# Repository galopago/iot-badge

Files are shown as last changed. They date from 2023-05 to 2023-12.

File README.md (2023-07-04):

# IOT-BADGE

## Electronic conference badge for programming conventions, hacking events, etc.

* Open Source (designed in [KiCad](https://www.kicad.org/)), schematic files, PCB and GERBER files open, free and available
* Comfortable wearable badge, no components on the back side.
* Max size 10 x 10 cm to take advantage of cost reductions of most PCB makers.
* Can be powered by a 3.2 v LiFePO4 AAA size battery
* Compatible with TinyGS firmware for [reception of LoRa satellites](https://galopago.github.io/english/lora-satelite-ground-station/). No modifications needed!

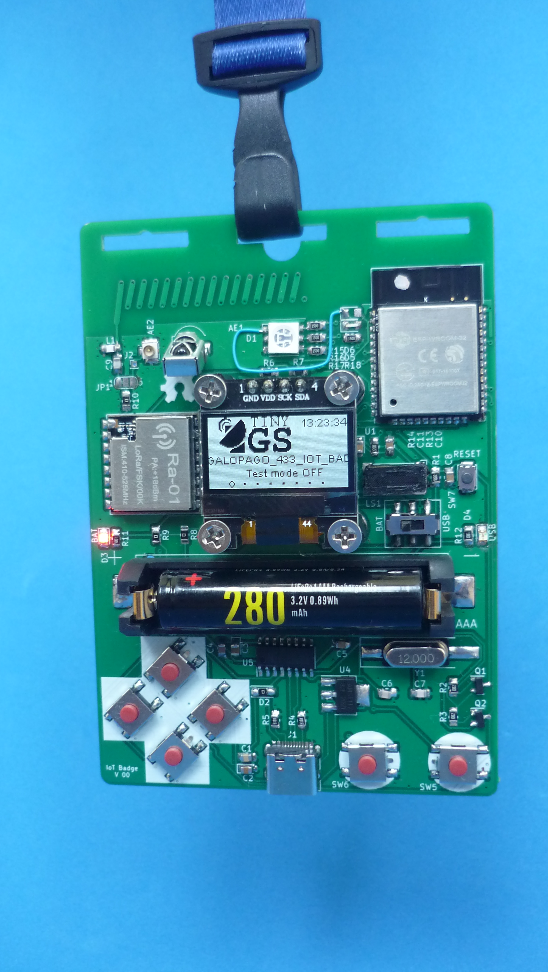
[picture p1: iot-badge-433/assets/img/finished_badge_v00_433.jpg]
Finished Badge 433 Mhz version


Read this in other languages: [Español](/iot-badge-433/assets/markdown/README.es.md)

## Block Diagram

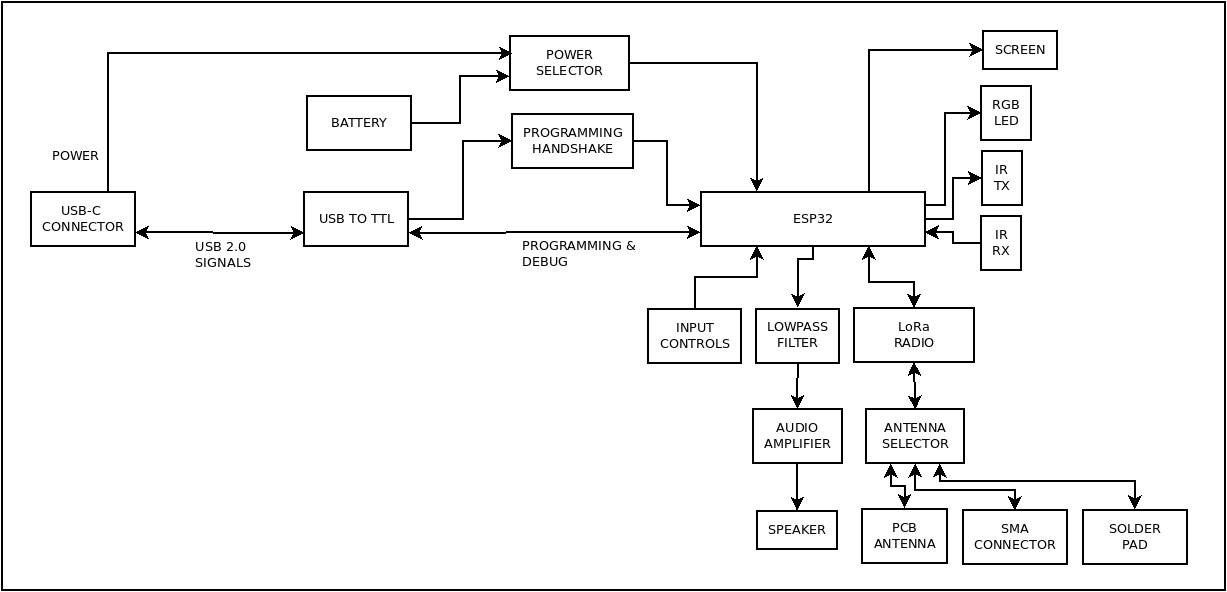
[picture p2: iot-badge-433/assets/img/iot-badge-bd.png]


## Capabilities

* ESP32 module compatible with multiple programming languages/platforms: [C/C++](https://docs.espressif.com/projects/esp-idf/en/latest/esp32/), [Arduino](https://github.com/espressif/arduino-esp32), Python (via [MicroPython](https://micropython.org/)), JavaScript (via [Espruino](https://www.espruino.com/ESP32) or [Mongoose OS](https://mongoose-os.com/)), [Rust ([via esp-rs](https://esp-rs.github.io/book/))
* 0.96" OLED display
* Infrared LED transmitter and receiver
* WiFi
* Radio transmitter and receiver module: FSK, GFSK, MSK, GMSK and LoRa!
* Onboard PCB antenna (433 Mhz and 915 Mhz versions)
* U.FL Connector for external antenna
* RGB LED
* 0.7 W speaker
* 6 buttons: 4 arranged in D-pad and 2 function buttons
* USB-C Connector

## 433 Mhz Version
Back                           | Side                                  | External Ant                          |
-------------------------------|---------------------------------------|---------------------------------------|
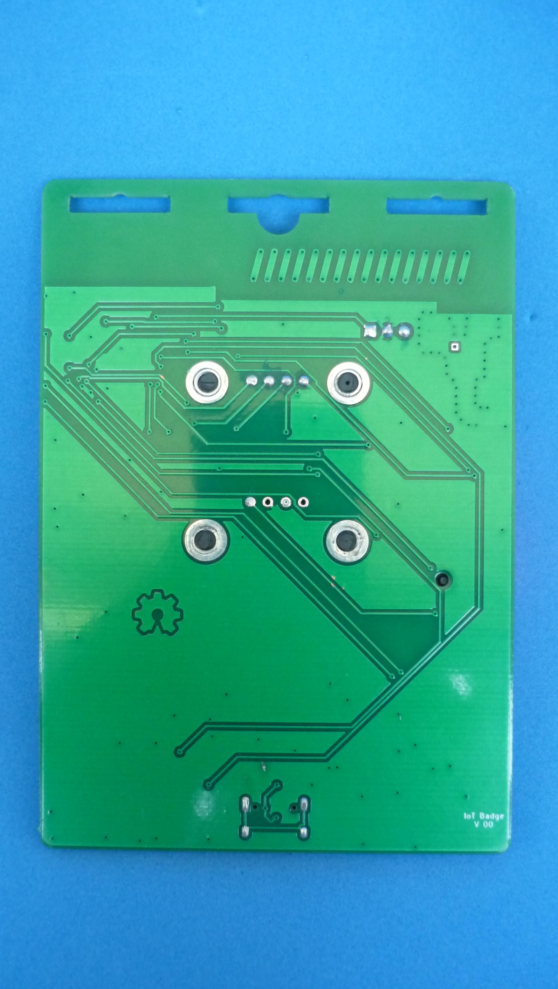
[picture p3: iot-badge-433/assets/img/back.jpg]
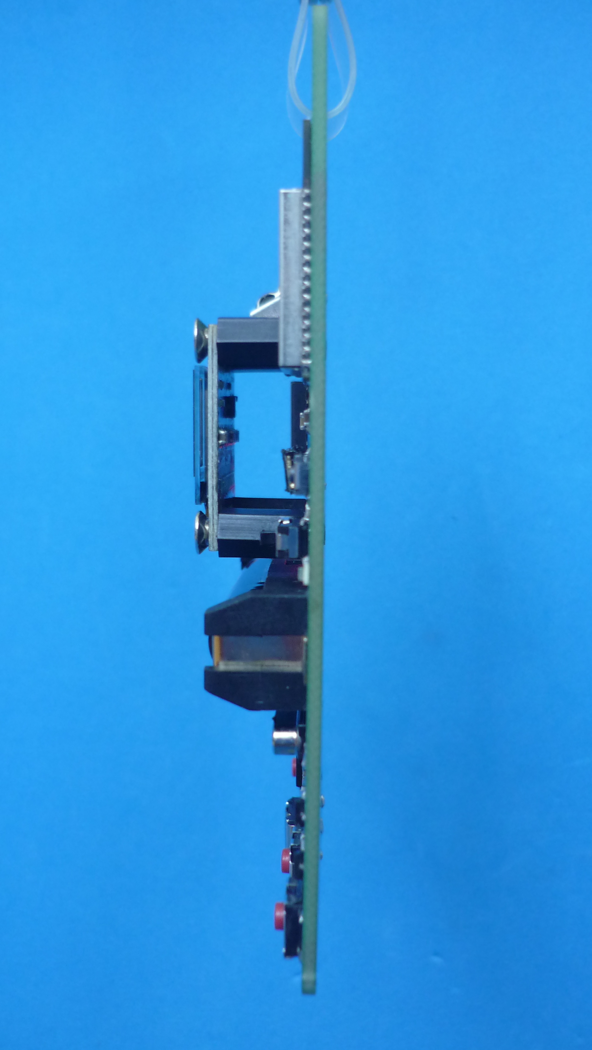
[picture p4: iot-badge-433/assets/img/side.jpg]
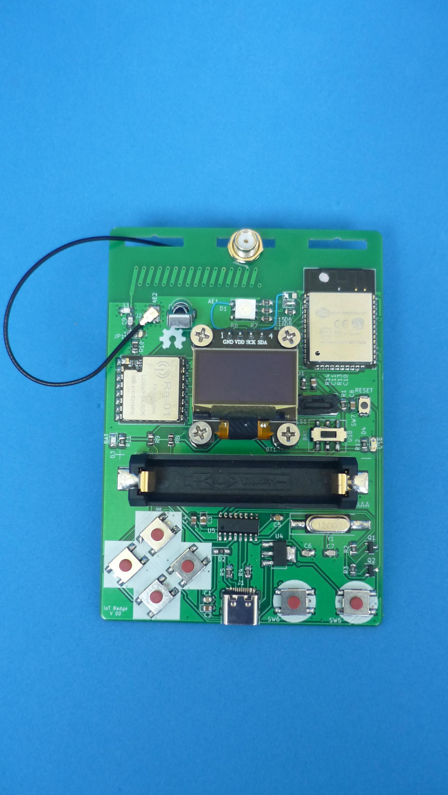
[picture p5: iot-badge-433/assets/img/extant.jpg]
| | |

## Schematic Diagram 433 Version

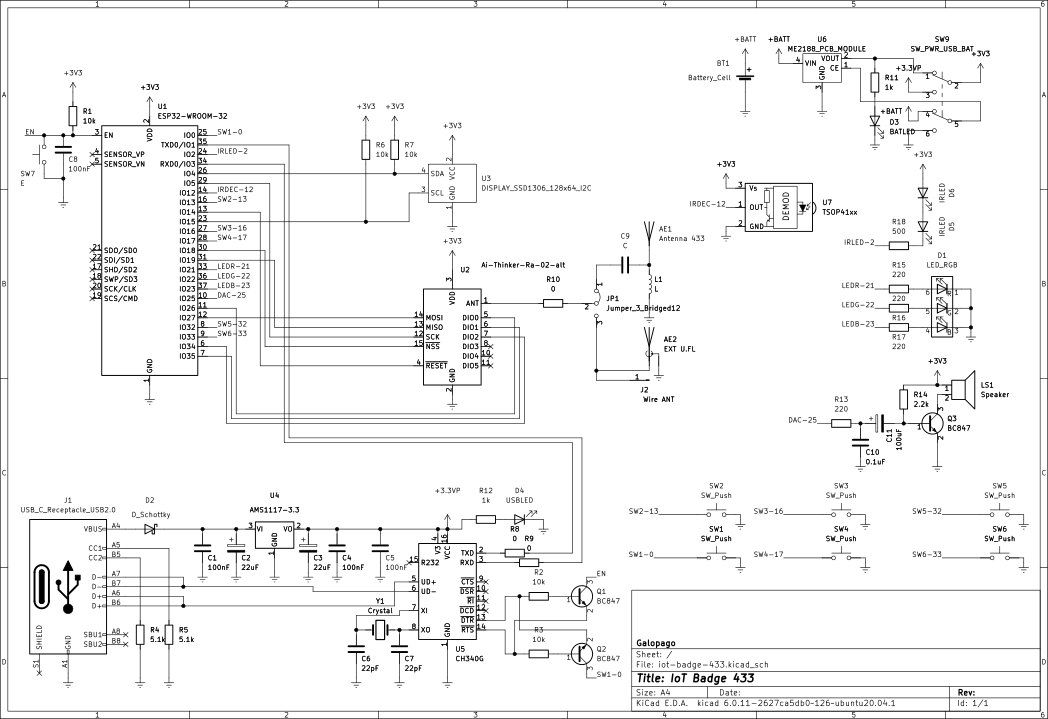
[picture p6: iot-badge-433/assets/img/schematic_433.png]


## Pinout connections

### SSD1306 128x64 i2c OLED display

ESP32 GPIO PIN |Function
---------------|---------
4              | SDA
15             | SCL

### Ra-02 LoRa module

ESP32 GPIO PIN |Function
---------------|---------
19             | POCI
27             | PICO
5              | SCK
18             | /CS

### Speaker

ESP32 GPIO PIN |Function
---------------|---------
25             | Speaker

### Buttons ( please use internal pull-ups! )

ESP32 GPIO PIN |Function
---------------|---------
0              | Up
13             | Down
16             | Left
17             | Right
33             | B
32             | A

### RGB LED

ESP32 GPIO PIN |Function
---------------|---------
21             | Red
22             | Green
23             | Blue

### Ifrared transmitter LED

ESP32 GPIO PIN |Function
---------------|---------
2              | Infrared LED

### VS1838b INFRARED RECEIVER MODULE

ESP32 GPIO PIN |Function
---------------|---------
12             | VS1838b output

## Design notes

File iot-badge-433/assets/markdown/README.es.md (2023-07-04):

# IOT-BADGE

## Gafete electronico para conferencias de programacion, eventos de hackers, etc.

* Codigo abierto (disenado en [KiCad](https://www.kicad.org/)), diagramas esquematicos, circuito impreso y archivos GERBER abiertos, gratuitos y disponibles!
* Comodo para usar, no hay componentes en la cara de atras del circuito impreso.
* Tamaño maximo 10 x 10 cm para lograr costos economicos en la fabricacion del circuito impreso que ofrecen la mayoria de fabricantes para tarjetas de dimensiones iguales o menores a esta.
* Puede ser alimentado mediante una bateria AAA LiFePO4 de 3.2 v.
* Compatible con el firmware de TinyGS [para reception de satelites LoRa ](https://galopago.github.io/espanol/lora-satelite-estacion-terrena/). No se requiere ninguna modificacion!

## Version 433 Mhz
Finished Badge

Lea esto en otros idiomas: [English](../../../README.md)

## Diagrama de bloques



## Perifericos disponibles

* Modulo ESP32 compatible con multiples lenguajes/plataformas de programacion: [C/C++](https://docs.espressif.com/projects/esp-idf/en/latest/esp32/), [Arduino](https://github.com/espressif/arduino-esp32), Python (via [MicroPython](https://micropython.org/)), JavaScript (via [Espruino](https://www.espruino.com/ESP32) or [Mongoose OS](https://mongoose-os.com/)), [Rust ([via esp-rs](https://esp-rs.github.io/book/))
* Pantalla OLED de 0.96"
* LED transmisor infrarojo y receptor.
* WiFi
* Modulo radio transmisor FSK, GFSK, MSK, GMSKde 433 Mhz y LoRa!
* Antena incorporada en el PCB (version de 433 Mhz y 915 Mhz)
* Conector U.FL para antena externa.
* LED RGB
* Bocina de 0.7 W
* 6 butone: 4 configurados como cruceta y 2 botones de funcion adicional
* Conector USB-C

Detras                         | Lateral                               | Antena Externa                        |
-------------------------------|---------------------------------------|---------------------------------------|
| | |

## Diagrama Esquematico



## Conexiones de pines entre los perifericos y el modulo ESP32

### Pantalla OLED i2c SSD1306 128x64

ESP32 GPIO PIN |Funcion
---------------|---------
4              | SDA
15             | SCL

### modulo LoRa Ra-02

ESP32 GPIO PIN |Funcion
---------------|---------
19             | POCI
27             | PICO
5              | SCK
18             | /CS

### Bocina

ESP32 GPIO PIN |Funcion
---------------|---------
25             | Bocina

### Butones ( hay que usar internos! )

ESP32 GPIO PIN |Funcion
---------------|---------
0              | Arriba
13             | Abajo
16             | Izquierda
17             | Derecha
33             | B
32             | A

### LED RGB

ESP32 GPIO PIN |Funcion
---------------|---------
21             | Rojo
22             | Verde
23             | Azul

### LED Infrarojo transmisor

ESP32 GPIO PIN |Funcion
---------------|---------
2              | LED Infrarojo

### MODULO RECEPTOR INFRAROJO VS1838b

ESP32 GPIO PIN |Funcion
---------------|---------
12             | salida del VS1838b

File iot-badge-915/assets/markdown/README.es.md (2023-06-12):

# IOT-BADGE

## Gafete electronico para conferencias de programacion, eventos de hackers, etc.

* Codigo abierto (disenado en [KiCad](https://www.kicad.org/)), diagramas esquematicos, circuito impreso y archivos GERBER abiertos, gratuitos y disponibles!
* Comodo para usar, no hay componentes en la cara de atras del circuito impreso.
* Tamaño maximo 10 x 10 cm para lograr costos economicos en la fabricacion del circuito impreso que ofrecen la mayoria de fabricantes para tarjetas de dimensiones iguales o menores a esta.
* Puede ser alimentado mediante una bateria AAA LiFePO4 de 3.2 v.
* Compatible con el firmware de TinyGS [para reception de satelites LoRa ](https://galopago.github.io/espanol/lora-satelite-estacion-terrena/). No se requiere ninguna modificacion!

Finished Badge

Lea esto en otros idiomas: [English](../../README.md)

## Diagrama de bloques



## Perifericos disponibles

* Modulo ESP32 compatible con multiples lenguajes/plataformas de programacion: [C/C++](https://docs.espressif.com/projects/esp-idf/en/latest/esp32/), [Arduino](https://github.com/espressif/arduino-esp32), Python (via [MicroPython](https://micropython.org/)), JavaScript (via [Espruino](https://www.espruino.com/ESP32) or [Mongoose OS](https://mongoose-os.com/)), [Rust ([via esp-rs](https://esp-rs.github.io/book/))
* Pantalla OLED de 0.96"
* LED transmisor infrarojo y receptor.
* WiFi
* Radio transmisor de 433 Mhz (incluyendo LoRa) conectado a una antena interna formada en el circuito impreso!
* Conector U.FL para antena externa de 433 Mhz.
* LED RGB
* Bocina de 0.7 W
* 6 butone: 4 configurados como cruceta y 2 botones de funcion adicional
* Conector USB-C

Detras                         | Lateral                               | Antena Externa                        |
-------------------------------|---------------------------------------|---------------------------------------|
| | |

## Diagrama Esquematico

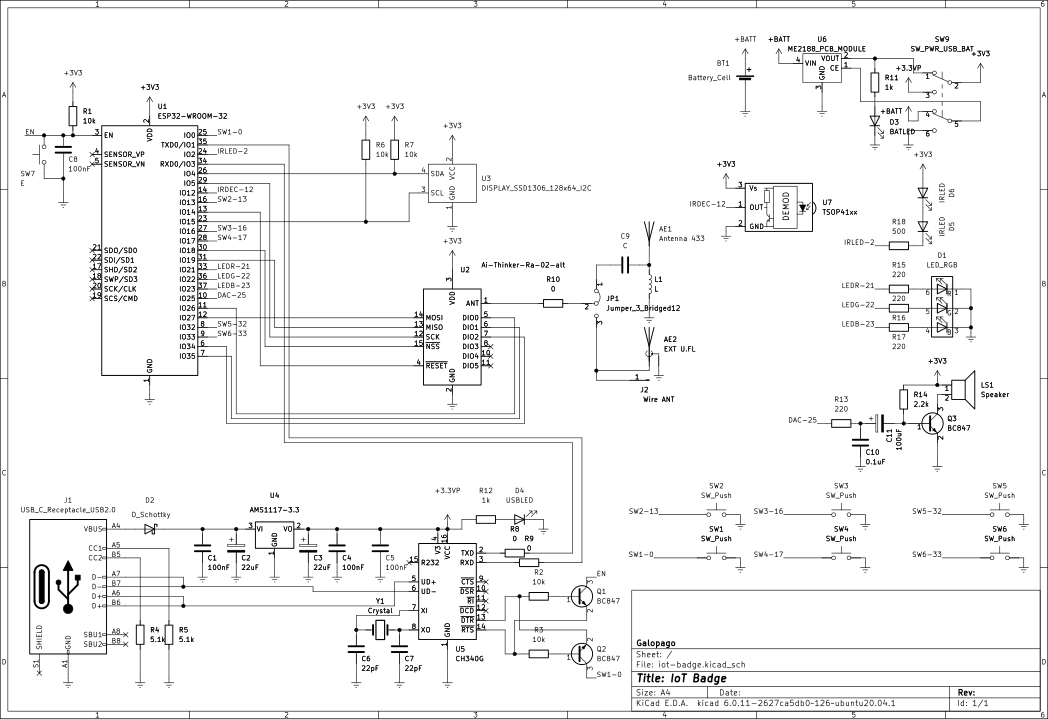
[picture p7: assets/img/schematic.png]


## Conexiones de pines entre los perifericos y el modulo ESP32

### Pantalla OLED i2c SSD1306 128x64

ESP32 GPIO PIN |Funcion
---------------|---------
4              | SDA
15             | SCL

### modulo LoRa Ra-02

ESP32 GPIO PIN |Funcion
---------------|---------
19             | POCI
27             | PICO
5              | SCK
18             | /CS

### Bocina

ESP32 GPIO PIN |Funcion
---------------|---------
25             | Bocina

### Butones ( hay que usar internos! )

ESP32 GPIO PIN |Funcion
---------------|---------
0              | Arriba
13             | Abajo
16             | Izquierda
17             | Derecha
33             | B
32             | A

### LED RGB

ESP32 GPIO PIN |Funcion
---------------|---------
21             | Rojo
22             | Verde
23             | Azul

### LED Infrarojo transmisor

ESP32 GPIO PIN |Funcion
---------------|---------
2              | LED Infrarojo

### MODULO RECEPTOR INFRAROJO VS1838b

ESP32 GPIO PIN |Funcion
---------------|---------
12             | salida del VS1838b

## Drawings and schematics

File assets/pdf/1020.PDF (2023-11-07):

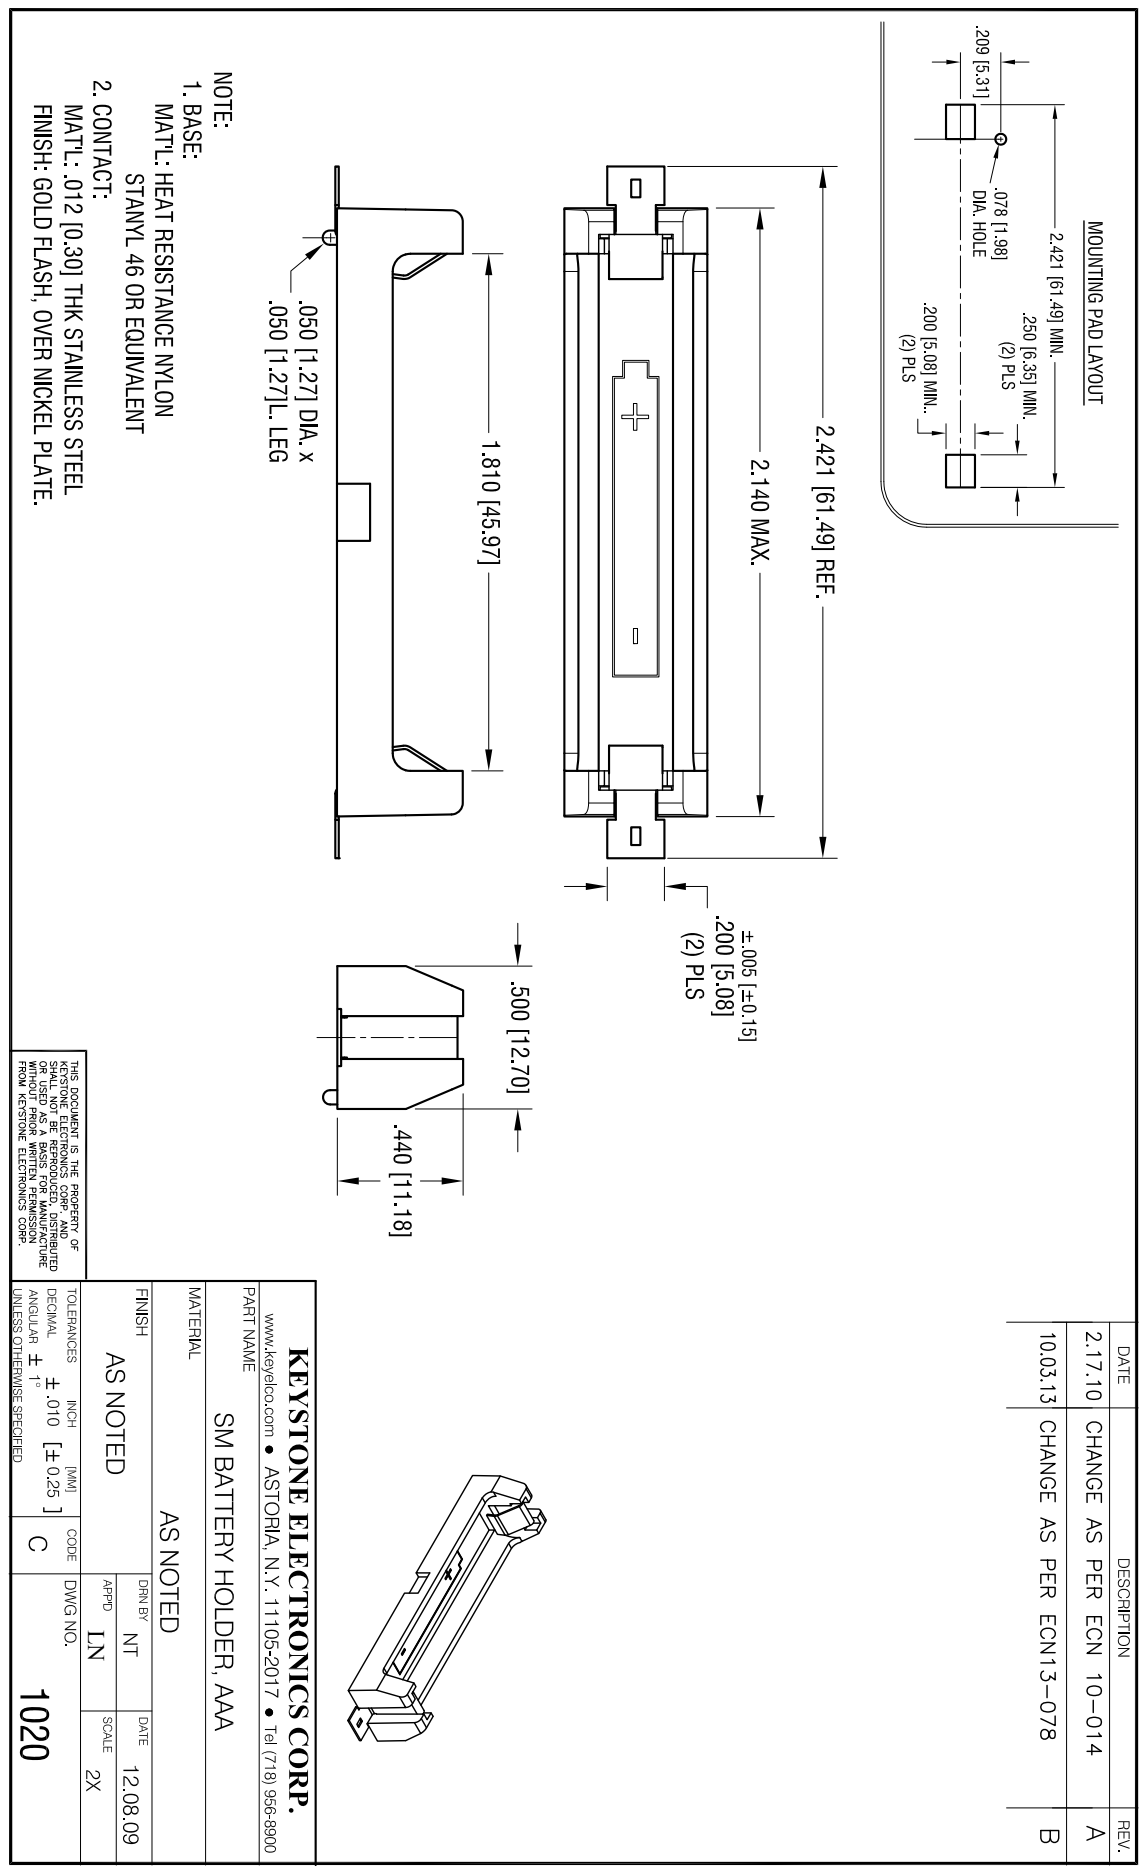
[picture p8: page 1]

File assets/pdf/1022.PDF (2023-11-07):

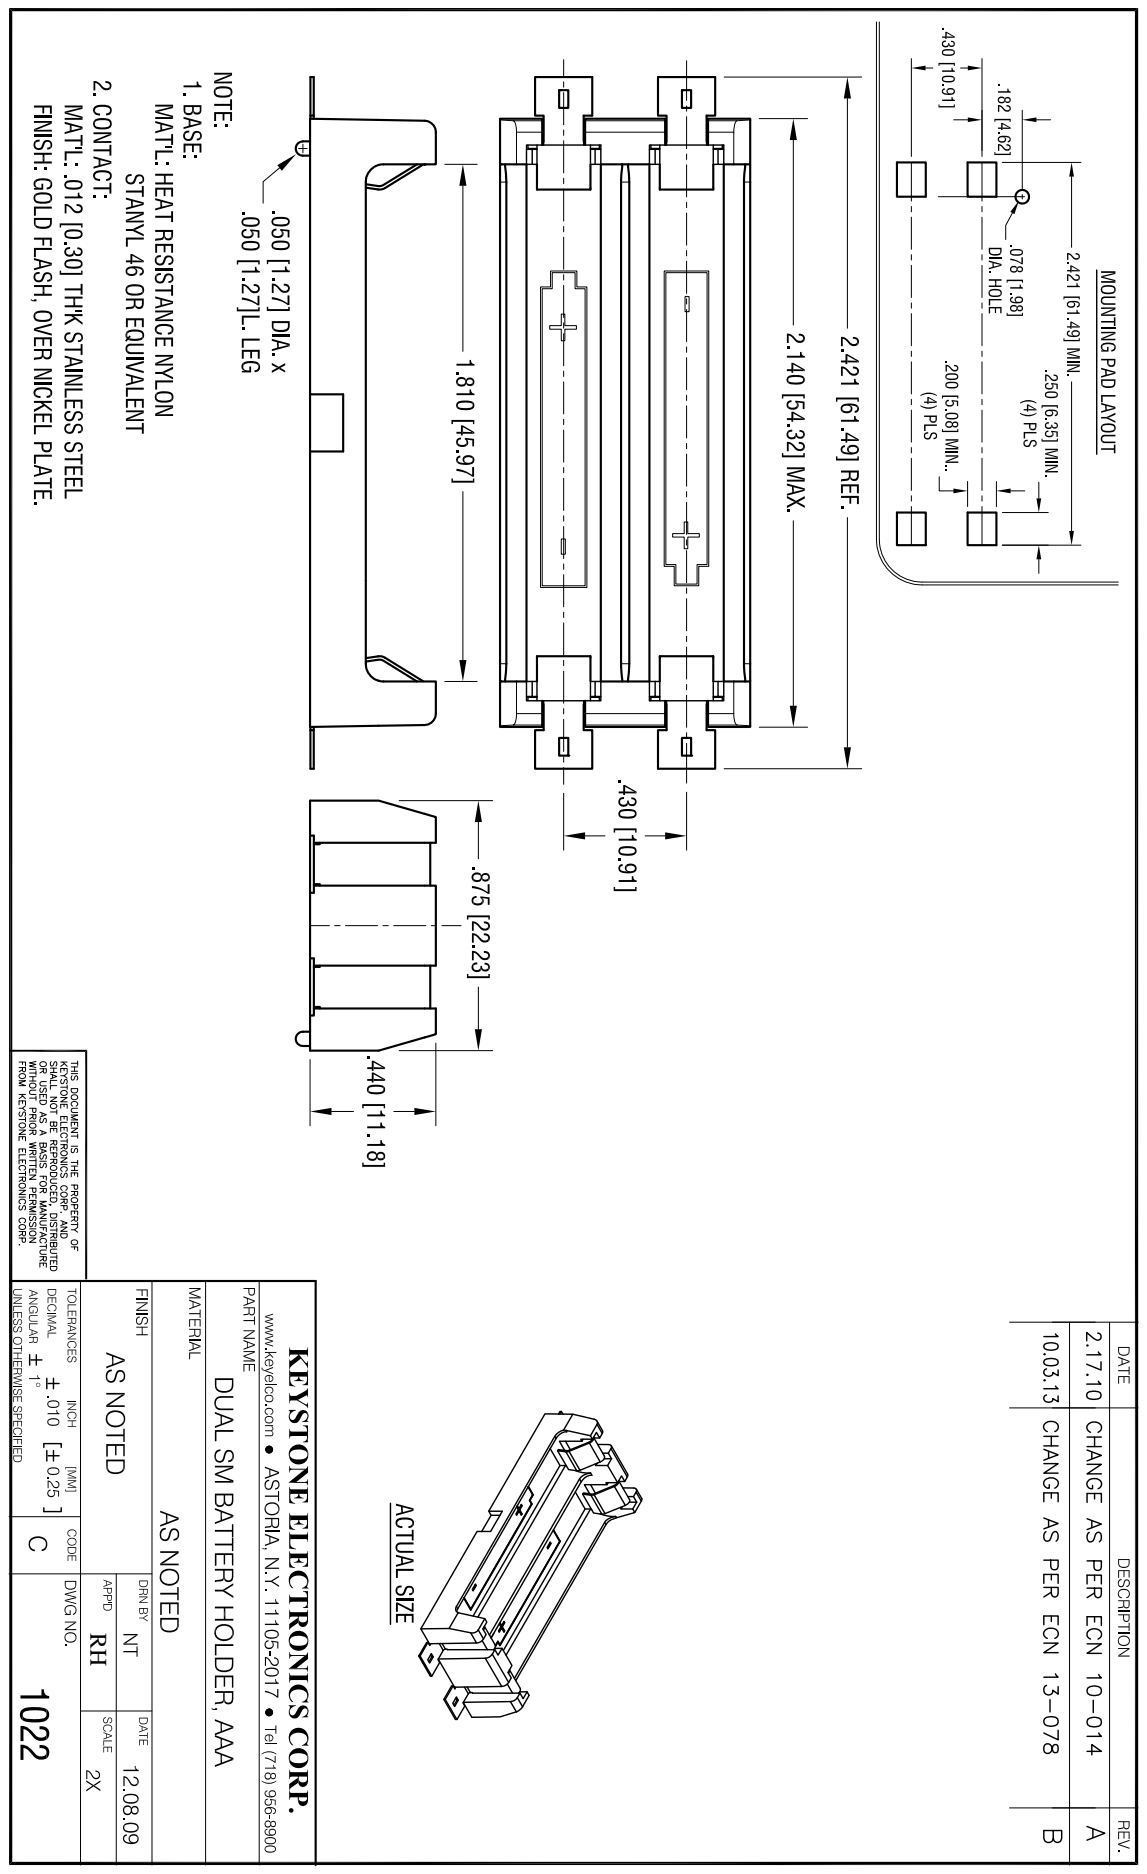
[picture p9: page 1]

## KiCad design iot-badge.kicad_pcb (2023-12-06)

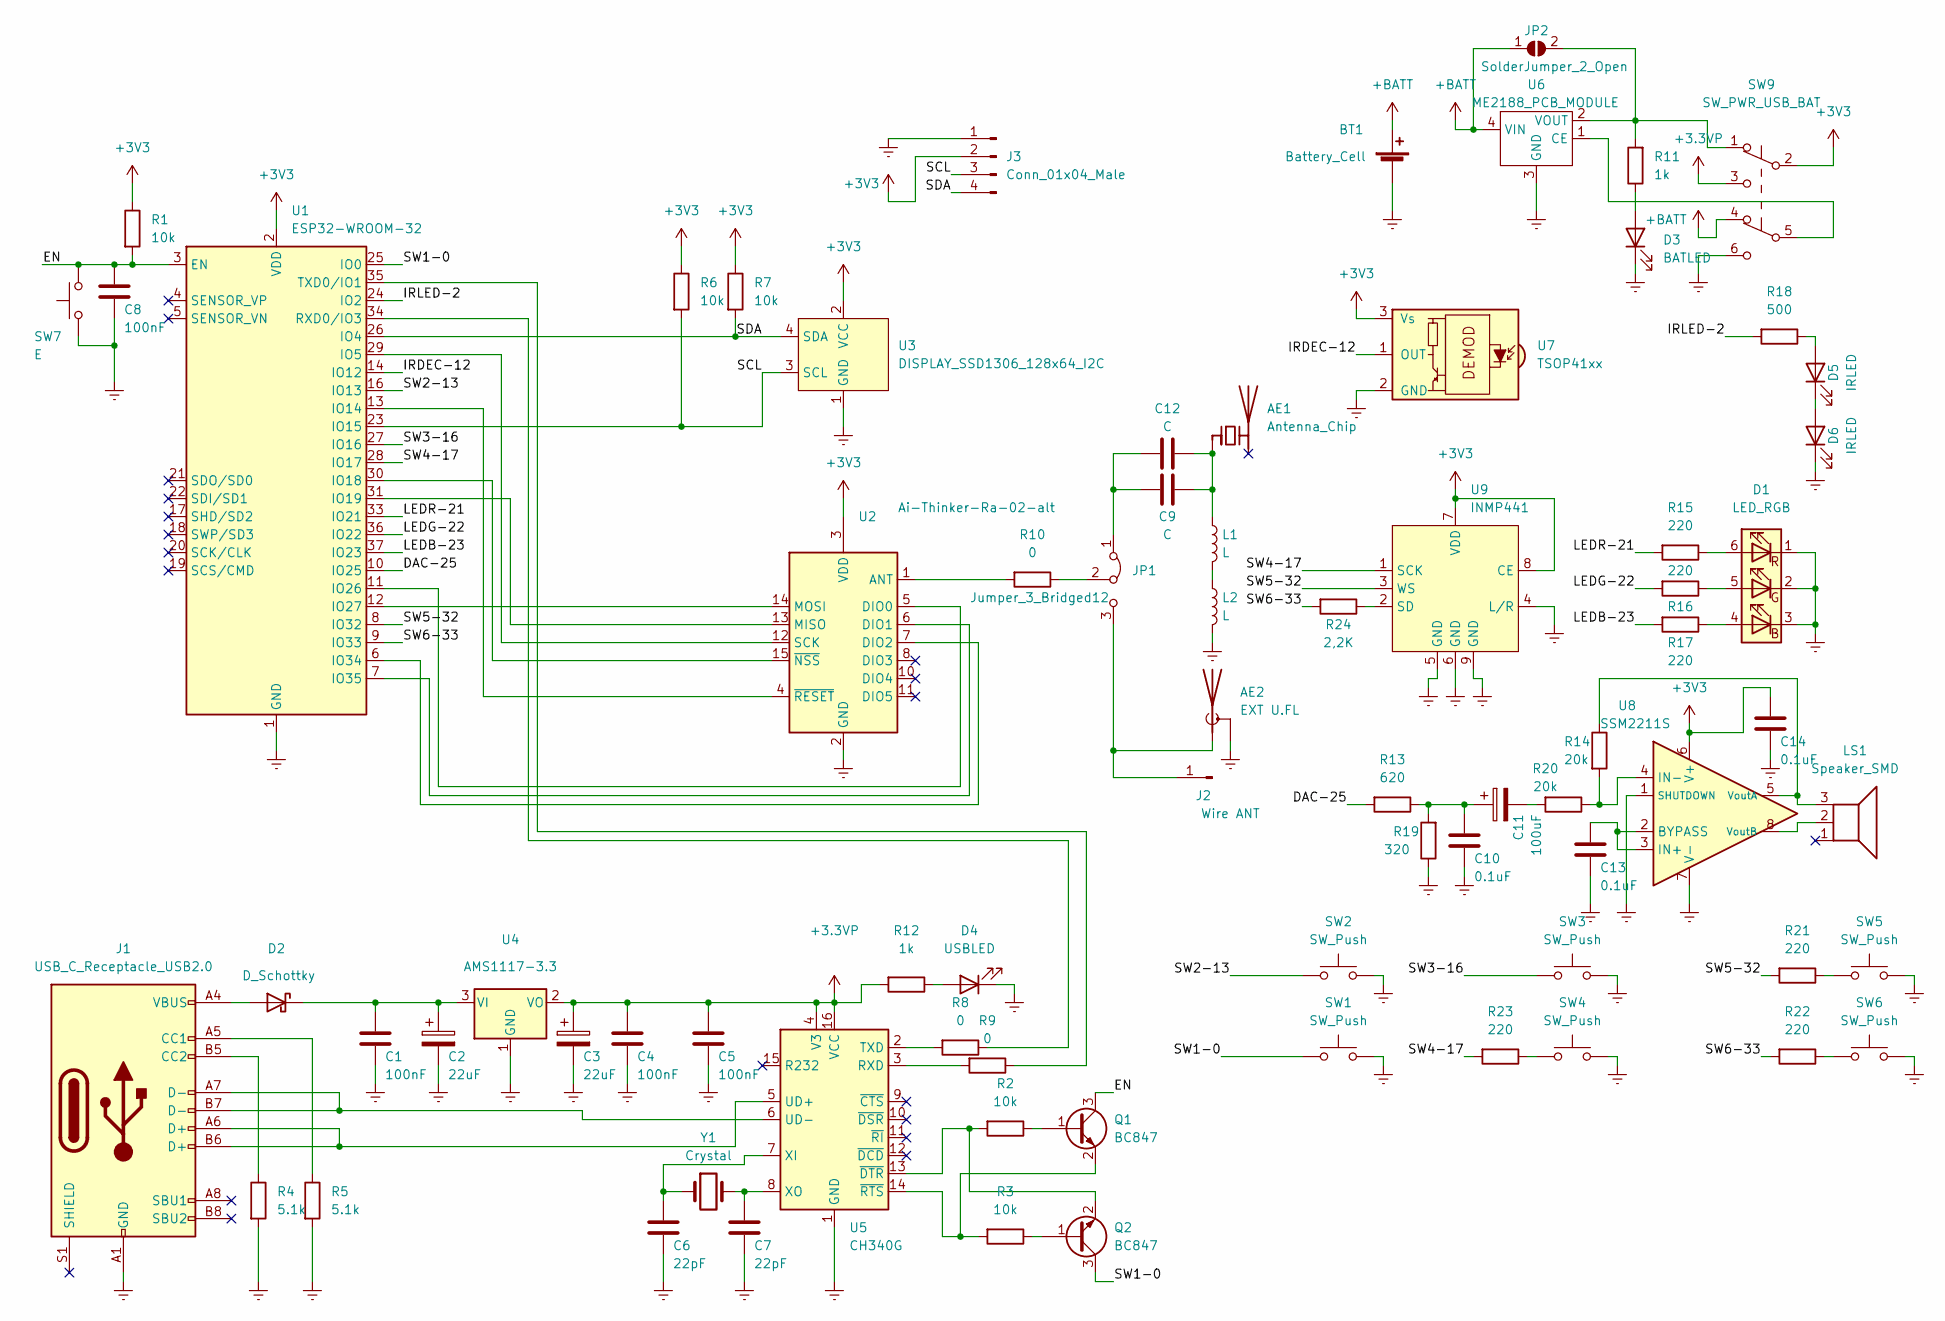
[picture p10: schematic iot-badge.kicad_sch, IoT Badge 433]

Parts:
AE1: Antenna_Chip; Crossair_ca-s01
AE2: EXT U.FL; U.FL_Hirose_U.FL-R-SMT-1_Vertical
BT1: Battery_Cell; BatteryHolder_Keystone_1022_2xAAA
C1, C4, C5, C8: 100nF; C_0805_2012Metric_Pad1.18x1.45mm_HandSolder
C2, C3: 22uF; CP_EIA-2012-15_AVX-P_Pad1.30x1.05mm_HandSolder
C6, C7: 22pF; C_0805_2012Metric_Pad1.18x1.45mm_HandSolder
C9, C12: C; C_0805_2012Metric_Pad1.18x1.45mm_HandSolder
C10, C13, C14: 0.1uF; C_0805_2012Metric_Pad1.18x1.45mm_HandSolder
C11: 100uF; CP_EIA-2012-15_AVX-P_Pad1.30x1.05mm_HandSolder
D1: LED_RGB; LED_RGB_5050-6
D2: D_Schottky; D_SOD-123
D3: BATLED; LED_0805_2012Metric_Pad1.15x1.40mm_HandSolder
D4: USBLED; LED_0805_2012Metric_Pad1.15x1.40mm_HandSolder
D5, D6: IRLED; LED_0805_2012Metric_Pad1.15x1.40mm_HandSolder
J1: USB_C_Receptacle_USB2.0; USB_C_Receptacle_HRO_TYPE-C-31-M-12
J2: Wire ANT; PinHeader_1x01_P1.00mm_Vertical
J3: Conn_01x04_Male; PinHeader_1x04_P2.54mm_Vertical
JP1: Jumper_3_Bridged12; SolderJumper-3_P1.3mm_Bridged12_RoundedPad1.0x1.5mm_NumberL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
JP2: SolderJumper_2_Open; SolderJumper-2_P1.3mm_Open_RoundedPad1.0x1.5mm
L1, L2: L; L_0805_2012Metric_Pad1.05x1.20mm_HandSolder
LS1: Speaker_SMD; Speaker_SMD-5020
Q1, Q2: BC847; SOT-23
R1, R2, R3, R6, R7: 10k; R_0805_2012Metric_Pad1.20x1.40mm_HandSolder
R4, R5: 5.1k; R_0805_2012Metric_Pad1.20x1.40mm_HandSolder
R8, R9, R10: 0; R_0805_2012Metric_Pad1.20x1.40mm_HandSolder
R11, R12: 1k; R_0805_2012Metric_Pad1.20x1.40mm_HandSolder
R13: 620; R_0805_2012Metric_Pad1.20x1.40mm_HandSolder
R14, R20: 20k; R_0805_2012Metric_Pad1.20x1.40mm_HandSolder
R15, R16, R17, R21, R22, R23: 220; R_0805_2012Metric_Pad1.20x1.40mm_HandSolder
R18: 500; R_0805_2012Metric_Pad1.20x1.40mm_HandSolder
R19: 320; R_0805_2012Metric_Pad1.20x1.40mm_HandSolder
R24: 2,2K; R_0805_2012Metric_Pad1.20x1.40mm_HandSolder
SW1, SW2, SW3, SW4, SW5, SW6: SW_Push; SW_Push_1P1T_NO_6x6mm_H9.5mm
SW7: E; SW_Push_SPST_NO_Alps_SKRK
SW9: SW_PWR_USB_BAT; SW_Slide_2P2T_9mmx7.6mm
U1: ESP32-WROOM-32
U2: Ai-Thinker-Ra-02-alt; Ai-Thinker-Ra-02-LoRa-alt
U3: DISPLAY_SSD1306_128x64_I2C; DISPLAY_SSD1306_128x64_I2C_0.96inch
U4: AMS1117-3.3; SOT-223-3_TabPin2
U5: CH340G; SOIC-16_3.9x9.9mm_P1.27mm
U6: ME2188_PCB_MODULE
U7: TSOP41xx; Vishay_MOLD-3Pin
U8: SSM2211S; SOIC-8_3.9x4.9mm_P1.27mm
U9: INMP441
Y1: Crystal; Crystal_SMD_HC49-SD_HandSoldering_Compact

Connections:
+3.3VP: C3.1, C4.1, C5.1, R12.2, SW9.3 (C), U4.2 (VO), U5.4 (V3), U5.16 (VCC)
+3V3: C14.1, J3.2, R1.1, R6.1, R7.1, SW9.2 (B), U1.2 (VDD), U2.3 (VDD), U3.2 (VCC), U7.3 (Vs), U8.6 (V+), U9.7 (VDD), U9.8 (CE)
+BATT: BT1.1 (+), JP2.1 (A), SW9.4 (A), U6.4 (VIN)
/DAC-25: R13.2, U1.10 (IO25)
/EN: C8.1, Q1.3 (C), R1.2, SW7.2, U1.3 (EN)
/IRDEC-12: U1.14 (IO12), U7.1 (OUT)
/IRLED-2: R18.2, U1.24 (IO2)
/LEDB-23: R17.2, U1.37 (IO23)
/LEDG-22: R16.2, U1.36 (IO22)
/LEDR-21: R15.2, U1.33 (IO21)
/SCL: J3.3, R6.2, U1.23 (IO15), U3.3 (SCL)
/SDA: J3.4, R7.2, U1.26 (IO4), U3.4 (SDA)
/SW1-0: Q2.3 (C), SW1.1, U1.25 (IO0)
/SW2-13: SW2.1, U1.16 (IO13)
/SW3-16: SW3.1, U1.27 (IO16)
/SW4-17: R23.2, U1.28 (IO17), U9.1 (SCK)
/SW5-32: R21.2, U1.8 (IO32), U9.3 (WS)
/SW6-33: R22.2, R24.2, U1.9 (IO33)
Earth: AE2.2 (Shield), BT1.2 (-), C1.2, C2.2, C3.2, C4.2, C5.2, C6.2, C7.2, C8.2, C10.2, C13.2, C14.2, D1.1 (RK), D1.2 (GK), D1.3 (BK), D3.1 (K), D4.1 (K), D6.1 (K), J1.A1 (GND), J1.A12 (GND), J1.B1 (GND), J1.B12 (GND), J3.1, L2.2, R4.2, R5.2, R19.1, SW1.2, SW2.2, SW3.2, SW4.2, SW5.2, SW6.2, SW7.1, SW9.6 (C), U1.1 (GND), U1.15 (GND), U1.38 (GND), U1.39 (GND), U2.2 (GND), U2.9 (GND), U2.16 (GND), U3.1 (GND), U4.1 (GND), U5.1 (GND), U6.3 (GND), U7.2 (GND), U8.1 (SHUTDOWN), U8.7 (V-), U9.4 (L/R), U9.5 (GND), U9.6 (GND), U9.9 (GND)
unnamed: AE1.1 (FEED), C9.1, C12.1, L1.1
unnamed: AE2.1 (A), J2.1, JP1.3 (B)
unnamed: C1.1, C2.1, D2.1 (K), U4.3 (VI)
unnamed: C6.1, U5.7 (XI), Y1.1
unnamed: C7.1, U5.8 (XO), Y1.2
unnamed: C10.1, C11.1, R13.1, R19.2
unnamed: C11.2, R20.2
unnamed: C9.2, C12.2, JP1.1 (A)
unnamed: C13.1, U8.2 (BYPASS), U8.3 (IN+)
unnamed: D1.4 (BA), R17.1
unnamed: D1.5 (GA), R16.1
unnamed: D1.6 (RA), R15.1
unnamed: D2.2 (A), J1.A4 (VBUS), J1.A9 (VBUS), J1.B4 (VBUS), J1.B9 (VBUS)
unnamed: D3.2 (A), R11.1
unnamed: D4.2 (A), R12.1
unnamed: D5.1 (K), D6.2 (A)
unnamed: D5.2 (A), R18.1
unnamed: J1.A5 (CC1), R5.1
unnamed: J1.A6 (D+), J1.B6 (D+), U5.5 (UD+)
unnamed: J1.A7 (D-), J1.B7 (D-), U5.6 (UD-)
unnamed: J1.B5 (CC2), R4.1
unnamed: JP1.2 (C), R10.1
unnamed: JP2.2 (B), R11.2, SW9.1 (A), U6.2 (VOUT)
unnamed: L1.2, L2.1
unnamed: LS1.2, U8.8 (VoutB)
unnamed: LS1.3, R14.1, U8.5 (VoutA)
unnamed: Q1.1 (B), R2.1
unnamed: Q1.2 (E), R3.2, U5.14 (~RTS)
unnamed: Q2.1 (B), R3.1
unnamed: Q2.2 (E), R2.2, U5.13 (~DTR)
unnamed: R8.1, U1.34 (RXD0/IO3)
unnamed: R8.2, U5.2 (TXD)
unnamed: R9.1, U1.35 (TXD0/IO1)
unnamed: R9.2, U5.3 (RXD)
unnamed: R10.2, U2.1 (ANT)
unnamed: R14.2, R20.1, U8.4 (IN-)
unnamed: R21.1, SW5.1
unnamed: R22.1, SW6.1
unnamed: R23.1, SW4.1
unnamed: R24.1, U9.2 (SD)
unnamed: SW9.5 (B), U6.1 (CE)
unnamed: U1.6 (IO34), U2.7 (DIO2)
unnamed: U1.7 (IO35), U2.6 (DIO1)
unnamed: U1.11 (IO26), U2.5 (DIO0)
unnamed: U1.12 (IO27), U2.14 (MOSI)
unnamed: U1.13 (IO14), U2.4 (~RESET)
unnamed: U1.29 (IO5), U2.12 (SCK)
unnamed: U1.30 (IO18), U2.15 (~NSS)
unnamed: U1.31 (IO19), U2.13 (MISO)

Board: 2 copper layers, 77 parts (1 on the bottom side), 68 nets, no tracks yet.

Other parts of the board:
SYMB1: OSHW-Symbol_6.7x6mm_Copper
SYMB2: OSHW-Symbol_6.7x6mm_SilkScreen

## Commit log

2023-01-29 added first proof of concept
    [iot-badge.kicad_pcb, iot-badge.kicad_sch, iot-badge.sch]
2023-02-27 started readme
    [iot-badge.kicad_pcb, iot-badge.kicad_sch]
2023-03-01 started micrel pcb helix ant 433
    [projector-rx.GBL, projector-rx.GBO, projector-rx.GBS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]
2023-03-07 pcb antenna finished
    [iot-badge.kicad_pcb, iot-badge.kicad_sch]
2023-03-09 i2c display footprint started
    [iot-badge.kicad_pcb, iot-badge.kicad_sch]
2023-03-14 improved holding holes
    [iot-badge.kicad_pcb, iot-badge.kicad_sch]
2023-03-14 changed battery for AAA
    [iot-badge.kicad_pcb, iot-badge.kicad_sch]
2023-03-15 added some USB components
    [iot-badge.kicad_pcb, iot-badge.kicad_sch]
2023-03-22 ant needs some care NETS
    [iot-badge.kicad_pcb, iot-badge.kicad_sch]
2023-03-25 ant needs routing rules
    [iot-badge.dsn, iot-badge.kicad_pcb, iot-badge.kicad_sch]
2023-03-26 pcb ant fixed
    [iot-badge.dsn, iot-badge.kicad_pcb, iot-badge.kicad_sch]
2023-03-29 connected lora and screen
    [iot-badge.kicad_pcb, iot-badge.kicad_sch]
2023-03-31 added res buttons and almost routable
    [iot-badge.dsn, iot-badge.kicad_pcb, iot-badge.kicad_sch]
2023-04-19 added crystal and led rgb
    [iot-badge.kicad_pcb, iot-badge.kicad_sch]
2023-04-21 diode added to power
    [iot-badge.kicad_pcb, iot-badge.kicad_sch]
2023-04-26 added external ant
    [iot-badge.kicad_pcb, iot-badge.kicad_sch]
2023-04-29 power switch added
    [iot-badge.kicad_pcb, iot-badge.kicad_sch]
2023-05-01 added ground to pushbuttons
    [iot-badge.kicad_pcb, iot-badge.kicad_sch]
2023-05-02 started batt footprint
2023-05-03 all elements placed and wired
    [iot-badge.dsn, iot-badge.kicad_pcb, iot-badge.kicad_sch]
2023-05-04 silk improvements
    [iot-badge.kicad_pcb, iot-badge.kicad_sch]
2023-05-05 all wired, unable to route
    [iot-badge.dsn, iot-badge.kicad_pcb, iot-badge.kicad_sch]
2023-05-06 all wired, routed
    [iot-badge.kicad_pcb, iot-badge.kicad_sch, iot-badge00.dsn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]
2023-05-06 all wired, routed,fixes
    [iot-badge.kicad_pcb]
2023-05-08 finished pcb
    [iot-badge-B_Cu.gbr, iot-badge-B_Mask.gbr, iot-badge-B_Silkscreen.gbr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]
2023-05-08 gerber single
    [iot-badge-B_Cu.gbr, iot-badge-B_Mask.gbr, iot-badge-B_Silkscreen.gbr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]
2023-07-03 started 915 mhz pcb antenna
2023-07-03 finished uhf pcb antenna
2023-07-03 created iot badge VHF
    [iot-badge-vhf-B_Cu.gbr, iot-badge-vhf-B_Mask.gbr, iot-badge-vhf-B_Silkscreen.gbr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]
2023-07-03 created iot 433 and 915 versions (renamed)
    [iot-badge-433.dsn, iot-badge-433.kicad_pcb, iot-badge-433.kicad_sch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]
2023-07-03 915 version finished
    [iot-badge-915.kicad_pcb, iot-badge-915.kicad_sch]
2023-07-04 433 gerbers ok
    [iot-badge-433-B_Cu.gbr, iot-badge-433-B_Mask.gbr, iot-badge-433-B_Silkscreen.gbr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]
2023-07-04 915 gerbers ok
    [iot-badge-915-B_Cu.gbr, iot-badge-915-B_Mask.gbr, iot-badge-915-B_Silkscreen.gbr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]
2023-07-14 started smd 5020 buzzer footprint
2023-07-20 changed ir leds polarity, PSU silk and bypass jumper
    [iot-badge-433.kicad_pcb, iot-badge-433.kicad_sch, iot-badge-915.kicad_pcb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]
2023-07-20 added external i2c pins
    [iot-badge-433.kicad_pcb, iot-badge-433.kicad_sch, iot-badge-915.kicad_pcb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]
2023-07-20 shifted ant match elements to the left
    [iot-badge-433.kicad_pcb, iot-badge-915.kicad_pcb]
2023-07-21 added tuning cap an inductor to ant circuit
    [iot-badge-433.kicad_pcb, iot-badge-433.kicad_sch, iot-badge-915.kicad_pcb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]
2023-07-22 enlarged AAA bat footprint pads
    [iot-badge-433.kicad_pcb, iot-badge-915.kicad_pcb]
2023-08-13 added BTL amp to schematic
    [iot-badge-433.kicad_pcb, iot-badge-433.kicad_sch]
2023-08-13 audio amp elements routed
    [iot-badge-433.kicad_pcb, iot-badge-433.kicad_sch, iot-badge000.dsn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]
2023-08-15 added and routed audio components in 915mhz
    [iot-badge-915.kicad_pcb, iot-badge-915.kicad_sch]
2023-08-21 added i2s mems mic schematic and footprint
    [iot-badge-433.kicad_sch]
2023-08-22 moved xtal capacitors to make some room
    [iot-badge-433.kicad_pcb, iot-badge-915.kicad_pcb]
2023-08-22 added resistors to sw to protect against shorts
    [iot-badge-433.kicad_pcb, iot-badge-433.kicad_sch, iot-badge-915.kicad_pcb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]
2023-08-26 moved capacitors to make room
    [iot-badge-433.kicad_pcb, iot-badge-915.kicad_pcb]
2023-08-28 added resistor to switch
    [iot-badge-433.kicad_pcb, iot-badge-433.kicad_sch, iot-badge-915.kicad_pcb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]
2023-08-28 added i2s mic symbol
    [iot-badge-433.kicad_sch, iot-badge-915.kicad_sch]
2023-08-28 placed i2c mic in pcb
    [iot-badge-433.kicad_pcb, iot-badge-433.kicad_sch, iot-badge-915.kicad_pcb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]
2023-08-29 finished placing i2s mic
    [iot-badge-433.kicad_pcb, iot-badge-433.kicad_sch, iot-badge-915.kicad_pcb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]
2023-08-30 added some silk lines on back 433
    [iot-badge-433.kicad_pcb]
2023-08-31 added silks to 915 board
    [iot-badge-915.kicad_pcb]
2023-08-31 433 gerber
    [iot-badge-433-B_Cu.gbr, iot-badge-433-B_Mask.gbr, iot-badge-433-B_Silkscreen.gbr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]
2023-09-02 915 mhz single gerber
    [iot-badge-915-B_Cu.gbr, iot-badge-915-B_Mask.gbr, iot-badge-915-B_Silkscreen.gbr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]
2023-11-07 started to add new parts
    [iot-badge-433-B_Cu.gbr, iot-badge-433-B_Mask.gbr, iot-badge-433-B_Silkscreen.gbr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]
2023-11-08 aligned cross buttons
    [iot-badge.kicad_pcb]
2023-12-06 fixed crystal footprint and placed all components ok
    [iot-badge.kicad_pcb]
